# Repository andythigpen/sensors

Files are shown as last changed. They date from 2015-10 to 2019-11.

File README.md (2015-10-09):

# My MySensors Sensors...
Arduino code and supporting files for my [MySensors](http://mysensors.org) sensors (say that 5x fast).

## How the sensors are used

Each sensor node connects wirelessly to a MySensors Serial Gateway attached to a local install of [Home Assistant](https://home-assistant.io) (seen below).  
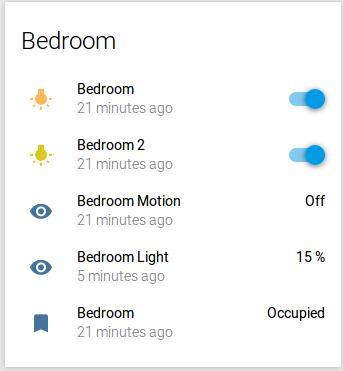
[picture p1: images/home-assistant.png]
Home Assistant


The PIR motion sensor is used to determine presence in a particular room, and the photocell light sensor is used to determine if the lights need to turn off or on based upon the ambient light level in the room and the current setting for the given time of day.  The state of the rooms and household is managed using a [custom Home Assistant module](https://github.com/andythigpen/hass-config/blob/master/custom_components/myhome.py).

## A Finished Sensor Node

### Front View
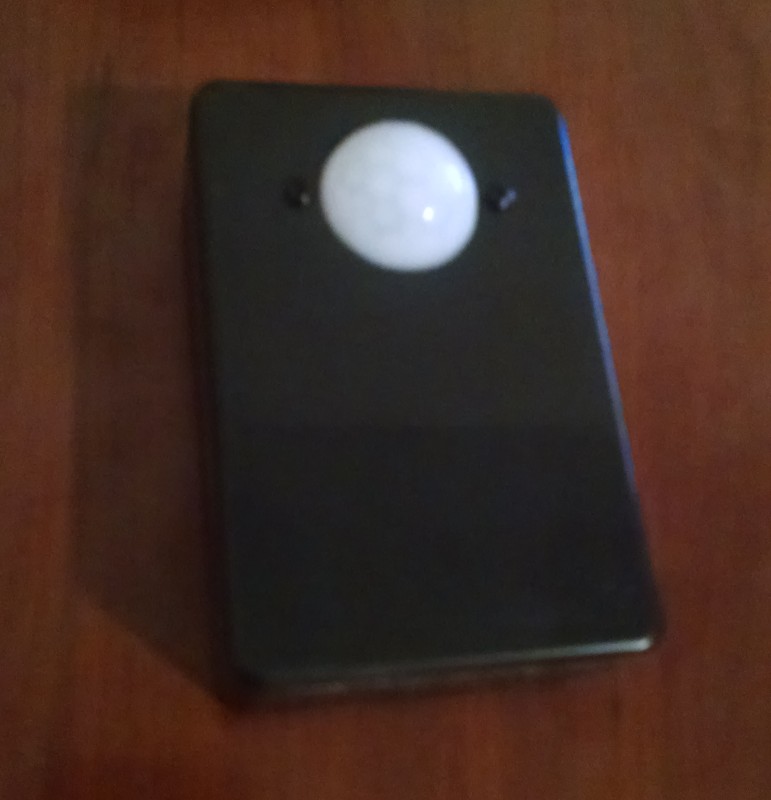
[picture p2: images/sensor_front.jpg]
Sensor Front


_Picture taken with a potato._

It's difficult to tell the size, but the project box is roughly the height and width of a pack of cards.

### Side View
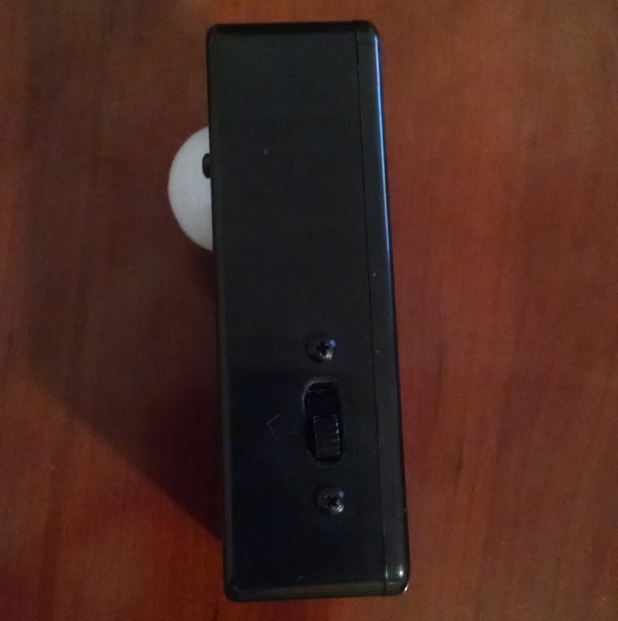
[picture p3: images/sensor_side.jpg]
Sensor Side


_Cutting square holes is harder than it looks._

### Guts View
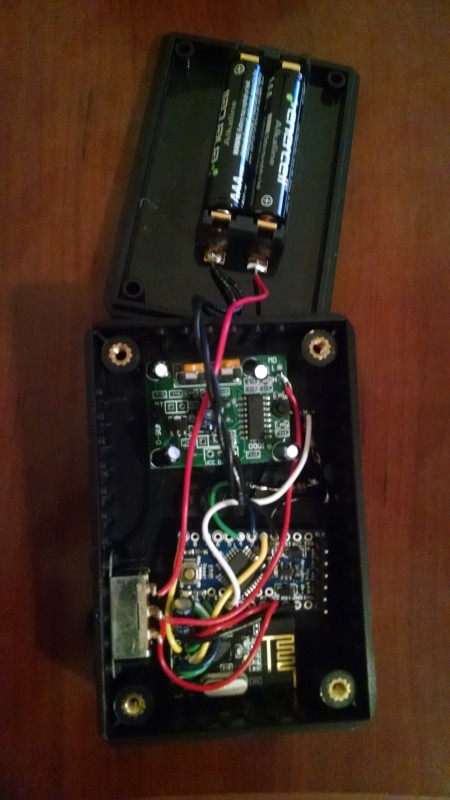
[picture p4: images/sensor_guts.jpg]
Sensor Guts


_It's not pretty but it works._

The battery holder is hot-glued to the lid, and the PIR sensor and power switch are fastened to the box using plastic screws/nuts.  The Arduino and nRF24 radio are not currently permanently attached as there isn't enough room inside the case to move around anyway.

### Schematic
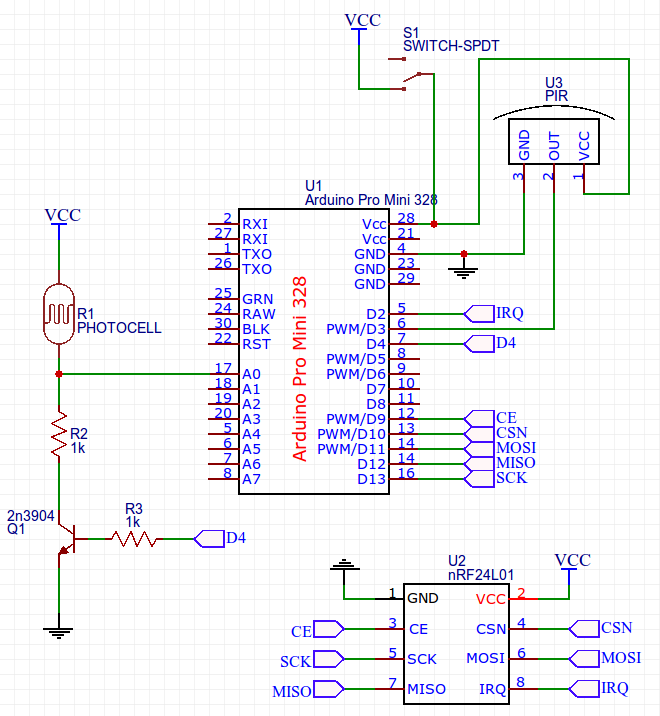
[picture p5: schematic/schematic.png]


## Project Layout
* images/ - pictures of a finished sensor node
* parts/ - CAD drawings of parts and layouts
* schematic/ - schematic files
* src/ - firmware source code

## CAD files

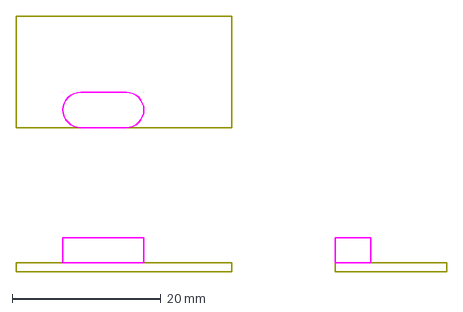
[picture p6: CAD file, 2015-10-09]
parts/#ITEAD-nRF24L01-module.dxf
58.0 x 34.4 mm

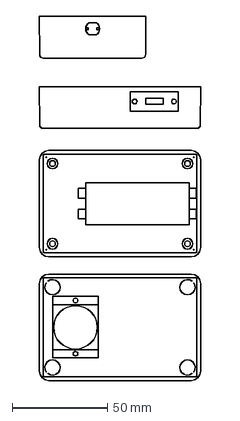
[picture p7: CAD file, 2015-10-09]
parts/sensor_box.dxf
84.8 x 191.6 mm

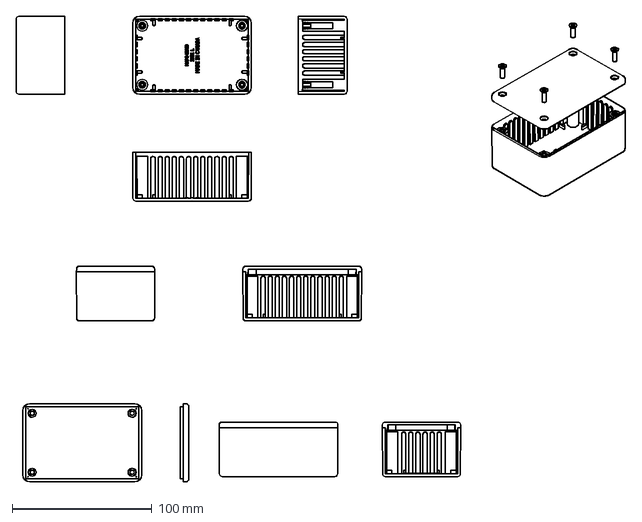
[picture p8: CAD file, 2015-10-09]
parts/1591L.dxf
436.6 x 333.4 mm

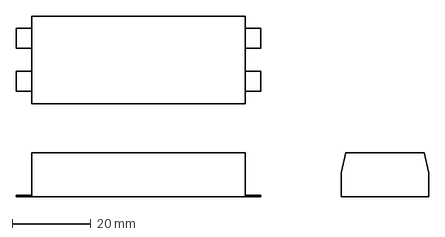
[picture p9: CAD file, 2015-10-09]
parts/1022_smd_aaa_battery_holder.dxf
104.9 x 46.0 mm

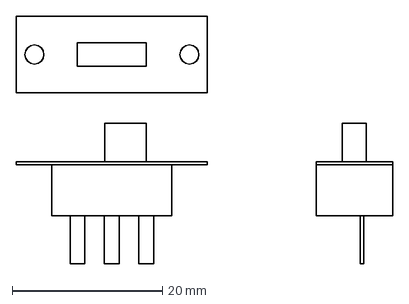
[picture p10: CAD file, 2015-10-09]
parts/spdt_switch.dxf
50.1 x 32.9 mm

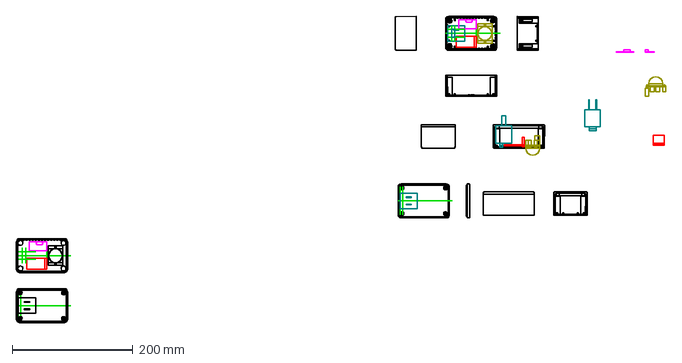
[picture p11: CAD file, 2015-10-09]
parts/sensor_box_large.dxf
1075.3 x 506.9 mm

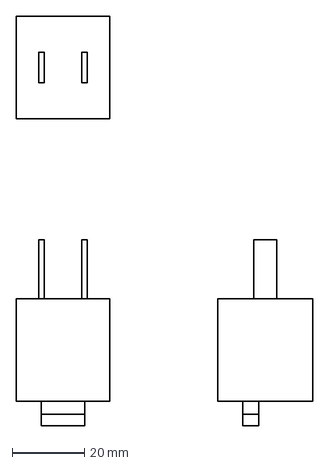
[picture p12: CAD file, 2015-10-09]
parts/apple_charger.dxf
82.2 x 113.7 mm

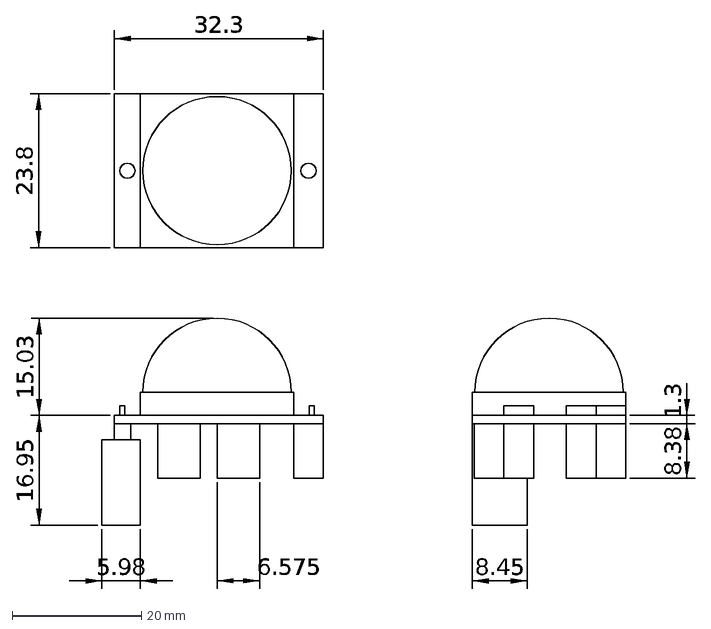
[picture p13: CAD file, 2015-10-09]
parts/pir_sensor.dxf
23.8
16.95
15.03
8.38
1.3
32.3
5.98
8.45
6.575

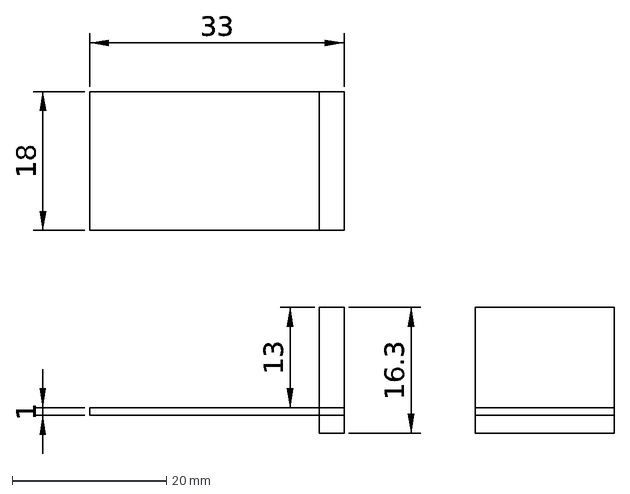
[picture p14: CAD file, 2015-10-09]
parts/arduino_pro_mini.dxf
33
18
16.3
1
13

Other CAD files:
parts/1591L.dwg
parts/ITEAD-nRF24L01-module.dxf

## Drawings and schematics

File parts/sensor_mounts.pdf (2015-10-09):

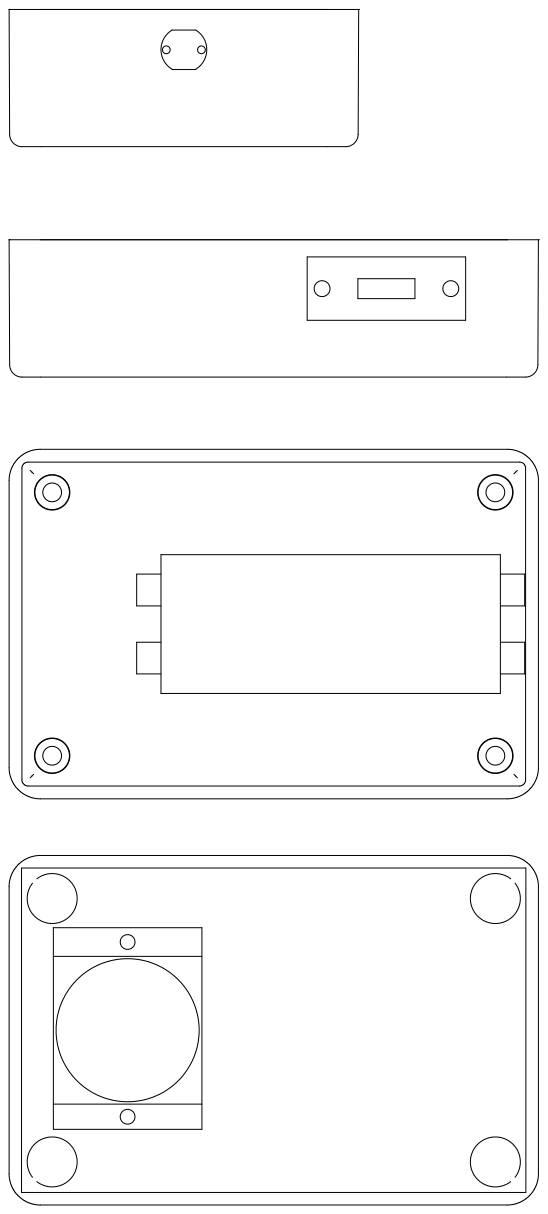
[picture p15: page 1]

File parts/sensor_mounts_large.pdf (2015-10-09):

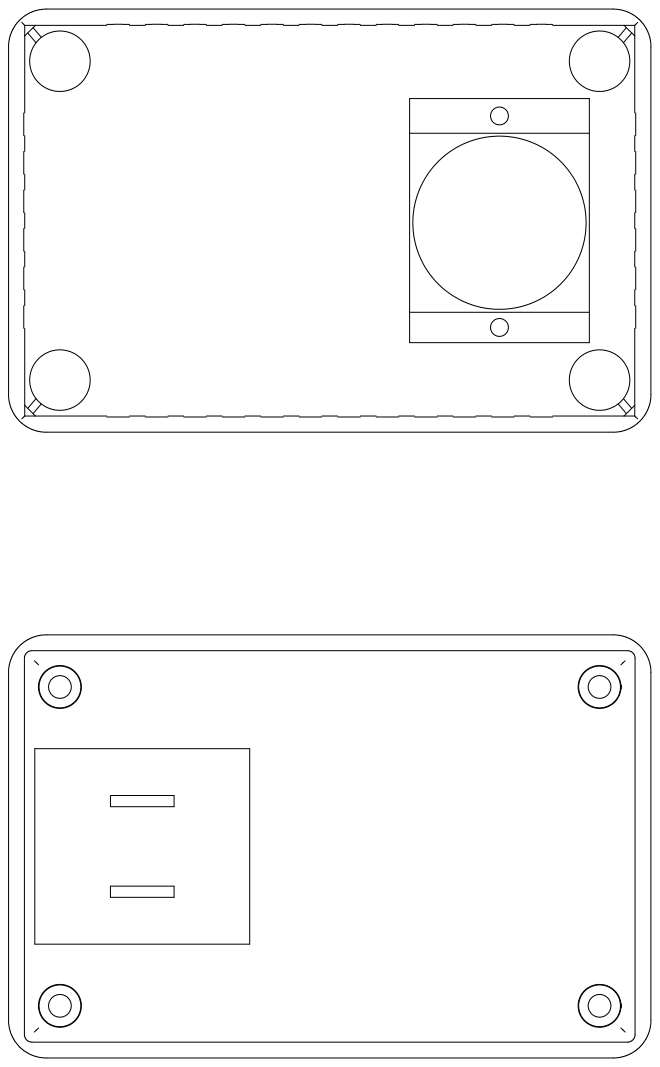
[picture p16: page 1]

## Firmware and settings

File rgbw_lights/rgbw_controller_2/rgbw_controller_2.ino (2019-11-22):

//
// RGBW Neopixel light controller
//
#include <Encoder.h>
#include <Adafruit_NeoPixel.h>
#include <MySensor.h>


// Configuration
#define SENSOR_VERSION      "1.2"
#define DEBUG               1
#define NUM_TOP_LEDS        56
#define NUM_BOTTOM_LEDS     34
#define DEFAULT_BRIGHTNESS  255
#define MAX_MODE            4
#define TIMEOUT_DEBOUNCE    50
#define TIMEOUT_LONG_PRESS  300
#define TIMEOUT_MODE        5000
#define TIMEOUT_STATUS      20000


// Pin definitions
#define PIN_ENC_A       3
#define PIN_ENC_B       A1
#define PIN_LED_R       4
#define PIN_LED_G       5
#define PIN_LED_B       A2
#define PIN_ENC_BTN     A0
#define PIN_NEO1_DIN    6
#define PIN_NEO2_DIN    7


// Sensors
#define MIN_CHILD        1
#define CHILD_TOP_ID     1
#define CHILD_BOTTOM_ID  2
#define MAX_CHILD        3


Encoder myEnc(PIN_ENC_A, PIN_ENC_B);
Adafruit_NeoPixel topStrip = Adafruit_NeoPixel(
    NUM_TOP_LEDS, PIN_NEO1_DIN, NEO_GRBW + NEO_KHZ800);
Adafruit_NeoPixel bottomStrip = Adafruit_NeoPixel(
    NUM_BOTTOM_LEDS, PIN_NEO2_DIN, NEO_GRBW + NEO_KHZ800);
MySensor gw;
MyMessage msg;


const uint8_t PROGMEM gamma8[] = {
    0,  0,  0,  0,  0,  0,  0,  0,  0,  0,  0,  0,  0,  0,  0,  0,
    0,  0,  0,  0,  0,  0,  0,  0,  0,  0,  0,  0,  1,  1,  1,  1,
    1,  1,  1,  1,  1,  1,  1,  1,  1,  2,  2,  2,  2,  2,  2,  2,
    2,  3,  3,  3,  3,  3,  3,  3,  4,  4,  4,  4,  4,  5,  5,  5,
    5,  6,  6,  6,  6,  7,  7,  7,  7,  8,  8,  8,  9,  9,  9, 10,
   10, 10, 11, 11, 11, 12, 12, 13, 13, 13, 14, 14, 15, 15, 16, 16,
   17, 17, 18, 18, 19, 19, 20, 20, 21, 21, 22, 22, 23, 24, 24, 25,
   25, 26, 27, 27, 28, 29, 29, 30, 31, 32, 32, 33, 34, 35, 35, 36,
   37, 38, 39, 39, 40, 41, 42, 43, 44, 45, 46, 47, 48, 49, 50, 50,
   51, 52, 54, 55, 56, 57, 58, 59, 60, 61, 62, 63, 64, 66, 67, 68,
   69, 70, 72, 73, 74, 75, 77, 78, 79, 81, 82, 83, 85, 86, 87, 89,
   90, 92, 93, 95, 96, 98, 99,101,102,104,105,107,109,110,112,114,
  115,117,119,120,122,124,126,127,129,131,133,135,137,138,140,142,
  144,146,148,150,152,154,156,158,160,162,164,167,169,171,173,175,
  177,180,182,184,186,189,191,193,196,198,200,203,205,208,210,213,
  215,218,220,223,225,228,231,233,236,239,241,244,247,249,252,255 };


// Modes
// 0 = brightness
// 1 = white
// 2 = red
// 3 = green
// 4 = blue
#define MODE_BRI  0
#define MODE_W    1
#define MODE_R    2
#define MODE_G    3
#define MODE_B    4


namespace timeout {
    long mode = 0;
    long debounce = 0;
    long longPress = 0;
    long status = 0;
    bool active = false;    // true when user is interacting w/ device

    void resetMode() {
        mode = millis() + TIMEOUT_MODE;
        active = true;
    }
};

namespace state {
    long encoder = 0;       // last position of the encoder
    bool button = LOW;      // last read of the button
    bool pressed = false;   // is a press event in progress
    bool longPress = false; // true when long press detected
    uint8_t mode = 0;       // current interface mode

    void setEncoder(long e) {
        encoder = e;
        myEnc.write(e);
    }

    void setMode(uint8_t m) {
        mode = m;
        if (mode > MAX_MODE)
            mode = 0;
#if DEBUG
        Serial.print("mode:");
        Serial.println(mode);
#endif
        switch (mode) {
            case 1:
                digitalWrite(PIN_LED_R, LOW);
                digitalWrite(PIN_LED_G, LOW);
                digitalWrite(PIN_LED_B, LOW);
                break;
            case 2:
                digitalWrite(PIN_LED_R, LOW);
                digitalWrite(PIN_LED_G, HIGH);
                digitalWrite(PIN_LED_B, HIGH);
                break;
            case 3:
                digitalWrite(PIN_LED_R, HIGH);
                digitalWrite(PIN_LED_G, LOW);
                digitalWrite(PIN_LED_B, HIGH);
                break;
            case 4:
                digitalWrite(PIN_LED_R, HIGH);
                digitalWrite(PIN_LED_G, HIGH);
                digitalWrite(PIN_LED_B, LOW);
                break;
            case 0:
            default:
                digitalWrite(PIN_LED_R, HIGH);
                digitalWrite(PIN_LED_G, HIGH);
                digitalWrite(PIN_LED_B, HIGH);
                break;
        }
    }

    void nextMode() {
        setMode(mode + 1);
    }
};

namespace lights {
    struct LightStrip {
        LightStrip(Adafruit_NeoPixel &s) : strip(s), color(0) {
            prevColor = strip.Color(0, 0, 0, 255);
            animation.color = strip.Color(0, 0, 0, 255);
            animation.bri = DEFAULT_BRIGHTNESS;
            animation.steps = 0;
            animation.duration = 1000000;
            //animation.duration = 0;
            animation.wait = 0;
            animation.prevFrame = 0;
        }
        uint32_t color;
        uint32_t prevColor;
        uint8_t prevBri;
        Adafruit_NeoPixel &strip;

        struct {
            uint32_t color;
            uint8_t bri;
            uint32_t steps;
            uint32_t duration;
            uint32_t wait;
            uint32_t prevFrame;
        } animation;

        void resetAnimation() {
            byte current, to, diff;

            animation.steps = 1;
            animation.prevFrame = 0;
            animation.wait = 0;

            // don't animate anything when interacting directly with the controller
            if (!timeout::active && animation.duration) {
                for (uint8_t i = 0; i < 4; ++i) {
                    current = *((byte *)&color + i);
                    to = *((byte *)&animation.color + i);
                    diff = current > to ? current - to : to - current;
                    animation.steps = max(animation.steps, diff);
#if DEBUG
                    Serial.print("i:");
                    Serial.print(i);
                    Serial.print(" current:");
                    Serial.print(current);
                    Serial.print(" to:");
                    Serial.print(to);
                    Serial.print(" diff:");
                    Serial.print(diff);
                    Serial.print(" steps:");
                    Serial.println(animation.steps);
#endif
                }

                current = strip.getBrightness();
                to = animation.bri;
                diff = current > to ? current - to : to - current;
                animation.steps = max(animation.steps, diff);
                animation.wait = animation.duration / animation.steps;
            }

#if DEBUG
            Serial.print("steps:");
            Serial.print(animation.steps);
            Serial.print(" wait:");
            Serial.print(animation.wait);
            Serial.print(" duration:");
            Serial.println(animation.duration);
#endif
        }

        void animate() {
            // do not use animations for direct interaction
            //if (timeout::active)
            //    animation.steps = 1;

            //if (timeout::active || (animation.steps && micros() - animation.prevFrame > animation.wait))
            if (animation.steps && micros() - animation.prevFrame > animation.wait)
                displayFrame();
        }

        void displayFrame() {
            byte *current, *to;

            animation.prevFrame = micros();
            animation.steps -= 1;

            if (animation.steps == 0) {
                color = animation.color;
                strip.setBrightness(animation.bri);
            }
            else {
                for (uint8_t i = 0; i < 4; ++i) {
                    current = (byte *)&color + i;
                    to = (byte *)&animation.color + i;

                    if (*current > *to)
                        *current -= 1;
                    else if (*current < *to)
                        *current += 1;
                }

                byte bri = strip.getBrightness();
                if (bri > animation.bri)
                    strip.setBrightness(bri - 1);
                else if (bri < animation.bri)
                    strip.setBrightness(bri + 1);
            }

            update();
            draw();
        }

        bool isOn() {
            return color != 0 && animation.bri != 0;
        }

        void getRGBW(char *rgbwStr) {
            sprintf(rgbwStr, "%.6X", color & 0xFFFFFF);
            sprintf(rgbwStr + 6, "%.2X", color >> 24);
        }

        void begin() {
            strip.setBrightness(DEFAULT_BRIGHTNESS);
            strip.begin();
            update();
            draw();
        }

        void update() {
#if 0
            Serial.print("update: ");
            Serial.print(strip.getPin());
            Serial.print(" color:");
            Serial.println(color, HEX);
#endif
            for (uint16_t i = 0; i < strip.numPixels(); ++i) {
                strip.setPixelColor(i, color);
            }
        }

        void toggle(uint8_t m) {
            if (get(m))
                set(m, 0);
            else
                set(m, 255);
#if DEBUG
            Serial.print("toggle: ");
            Serial.print(strip.getPin());
            Serial.print(" mode:");
            Serial.print(m);
            Serial.print(" val:");
            Serial.println(get(m));
#endif
            //update();
        }

        uint8_t get(uint8_t m) {
            switch (m) {
                case MODE_W: return ((uint8_t *)&color)[3];
                case MODE_R: return ((uint8_t *)&color)[2];
                case MODE_G: return ((uint8_t *)&color)[1];
                case MODE_B: return ((uint8_t *)&color)[0];
                case MODE_BRI: return strip.getBrightness();
                default: return 0;
            }
        }

        void set(uint8_t m, uint8_t val) {
            switch (m) {
                case MODE_W: ((uint8_t*)&animation.color)[3] = val; break;
                case MODE_R: ((uint8_t*)&animation.color)[2] = val; break;
                case MODE_G: ((uint8_t*)&animation.color)[1] = val; break;
                case MODE_B: ((uint8_t*)&animation.color)[0] = val; break;
                case MODE_BRI: animation.bri = val; break;
            }

            state::setEncoder(val);
#if DEBUG
            Serial.print("set: ");
            Serial.print(strip.getPin());
            Serial.print(" mode:");
            Serial.print(m);
            Serial.print(" val:");
            Serial.println(val);
#endif
            //update();
            resetAnimation();
        }

        void set(uint8_t r, uint8_t g, uint8_t b, uint8_t w) {
            animation.color = strip.Color(r, g, b, w);
            resetAnimation();
            //update();
        }

        void turnOn() {
            if (prevBri)
                animation.bri = prevBri;
            else
                animation.bri = 255;

            if (animation.color == 0)
                animation.color = strip.Color(0, 0, 0, 255);
            resetAnimation();
        }

        void turnOff() {
            prevBri = animation.bri;
            animation.bri = 0;
            resetAnimation();
        }

        void toggleSwitch(int val) {
            if (val)
                turnOn();
            else
                turnOff();
        }

        void draw() {
#if 0
            Serial.print("draw: ");
            Serial.println(strip.getPin());
#endif
            strip.show();
        }
    };
    LightStrip top(topStrip);
    LightStrip bottom(bottomStrip);

    void updateAll() {
        top.update();
        bottom.update();
    }

    void toggleAll(uint8_t m) {
        if (m == MODE_BRI) {
            if (lights::top.isOn()) {
                lights::top.turnOff();
                lights::bottom.turnOff();
            }
            else {
                lights::top.turnOn();
                lights::bottom.turnOn();
            }
        }
        else {
            lights::top.toggle(m);
            lights::bottom.toggle(m);
        }
    }

    void setAll(uint8_t m, uint8_t val) {
        lights::top.set(m, val);
        lights::bottom.set(m, val);
    }

    void drawAll() {
        top.draw();
        bottom.draw();
    }
};


void setup() {
    gw.begin(receiveMessage, 15);
    gw.sendSketchInfo("RGBW", SENSOR_VERSION);
    gw.present(CHILD_TOP_ID, S_RGBW_LIGHT);
    gw.present(CHILD_BOTTOM_ID, S_RGBW_LIGHT);

    sendStatus();

#if DEBUG
    Serial.println("RGBW Controller start");
#endif

    // setup encoder pins
    pinMode(PIN_LED_R, OUTPUT);
    pinMode(PIN_LED_G, OUTPUT);
    pinMode(PIN_LED_B, OUTPUT);
    pinMode(PIN_ENC_BTN, INPUT);

    digitalWrite(PIN_LED_R, HIGH);
    digitalWrite(PIN_LED_G, HIGH);
    digitalWrite(PIN_LED_B, HIGH);

    lights::top.begin();
    lights::bottom.begin();
}


void loop() {
    readButton();
    readEncoder();

    if (timeout::active && millis() > timeout::mode)
        onTimeoutMode();

    if (millis() > timeout::status)
        onTimeoutStatus();

    lights::top.animate();
    lights::bottom.animate();

    gw.process();
}


// Called when interface timer expires
void onTimeoutMode() {
#if DEBUG
    Serial.println("timeout mode");
#endif
    state::setMode(0);
    state::setEncoder(lights::top.get(state::mode));
    sendStatus();
    timeout::active = false;
}

// Called when status timer expires
void onTimeoutStatus() {
#if DEBUG
    Serial.println("timeout status");
#endif
    sendStatus();
    timeout::status = millis() + TIMEOUT_STATUS;
}


// Reads the button state and performs an action on change
void readButton() {
    bool btn = digitalRead(PIN_ENC_BTN);

    // button press start
    if (btn == HIGH && state::button == LOW &&
        (millis()  > timeout::debounce)) {
#if DEBUG
        Serial.println("press start");
#endif
        timeout::debounce = millis() + TIMEOUT_DEBOUNCE;
        timeout::longPress = millis() + TIMEOUT_LONG_PRESS;
        state::pressed = true;
        state::longPress = false;
    }

    if (state::pressed && (millis() > timeout::debounce)) {
        timeout::resetMode();

        if (millis() > timeout::longPress && !state::longPress) {
            onLongPress();
            state::longPress = true;
        }

        if (btn == LOW && state::button == HIGH) {
#if DEBUG
            Serial.println("press end");
#endif
            if (!state::longPress) {
                onShortPress();
            }
            state::pressed = false;
            timeout::debounce = millis() + TIMEOUT_DEBOUNCE;
        }
    }
    state::button = btn;
}


// Called on short button press events
void onShortPress() {
#if DEBUG
    Serial.println("short press");
#endif
    lights::toggleAll(state::mode);
    lights::drawAll();
}


// Called on long button press events
void onLongPress() {
#if DEBUG
    Serial.println("long press");
#endif
    state::nextMode();
    state::setEncoder(lights::top.get(state::mode));
}


// Handles on change event for encoder
void onChangeEncoder() {
#if DEBUG
    Serial.print("encoder:");
    Serial.print(state::encoder);
    Serial.print(" mode:");
    Serial.println(state::mode);
#endif
    lights::setAll(state::mode, state::encoder);
    lights::updateAll();
    lights::drawAll();
}

// Reads the encoder value and performs an action on change
void readEncoder() {
    long pos = myEnc.read();
    if (pos == state::encoder)
        return;

    if (pos > 255) {
        pos = 255;
        myEnc.write(255);
    }
    else if (pos < 0) {
        pos = 0;
        myEnc.write(0);
    }
    state::encoder = pos;
    timeout::resetMode();
    onChangeEncoder();
}

void sendStatus() {
    char rgbwStr[9];
    uint8_t val;

    // top light status
    msg.setSensor(CHILD_TOP_ID);
    msg.setType(V_RGBW);
    lights::top.getRGBW(rgbwStr);
    gw.send(msg.set(rgbwStr));

    msg.setType(V_STATUS);
    gw.send(msg.set(lights::top.isOn()));

    msg.setType(V_PERCENTAGE);
    val = lights::top.get(MODE_BRI);
    gw.send(msg.set(map(val, 0, 255, 0, 100)));

    msg.setType(V_VAR2);
    gw.send(msg.set(timeout::active));

    // bottom light status
    msg.setSensor(CHILD_BOTTOM_ID);
    msg.setType(V_RGBW);
    lights::bottom.getRGBW(rgbwStr);
    gw.send(msg.set(rgbwStr));

    msg.setType(V_STATUS);
    gw.send(msg.set(lights::bottom.isOn()));

    msg.setType(V_PERCENTAGE);
    val = lights::bottom.get(MODE_BRI);
    gw.send(msg.set(map(val, 0, 255, 0, 100)));

    msg.setType(V_VAR2);
    gw.send(msg.set(timeout::active));

    timeout::status = millis() + TIMEOUT_STATUS;
}

void receiveMessage(const MyMessage &message) {
    if (message.type == V_RGBW) {
        char rgbwStr[9];
        String hexstring = message.getString();
        hexstring.toCharArray(rgbwStr, sizeof(rgbwStr));

        unsigned long value = strtoul(rgbwStr, NULL, 16);
        byte w = value & 0xFF;
        byte r = value >> 24;
        byte g = value >> 16 & 0xFF;
        byte b = value >> 8 & 0xFF;

        if (message.sensor == CHILD_TOP_ID) {
            lights::top.set(r, g, b, w);
            //lights::top.setAnimation(new lights::FadeAnimation(&lights::top, lights::top.strip.Color(r, g, b, w), lights::animationDuration));
        }
        else if (message.sensor == CHILD_BOTTOM_ID) {
            lights::bottom.set(r, g, b, w);
            //lights::bottom.setAnimation(new lights::FadeAnimation(&lights::bottom, lights::bottom.strip.Color(r, g, b, w), lights::animationDuration));
        }

#if DEBUG
        Serial.print("child:");
        Serial.print(message.sensor);
        Serial.print(" V_RGBW:");
        Serial.println(value, HEX);
#endif

        // send optimistic response:
        msg.setSensor(message.sensor);
        msg.setType(V_RGBW);
        gw.send(msg.set(hexstring.c_str()));
    }

    if (message.type == V_STATUS) {
        int value = message.getInt();
        if (message.sensor == CHILD_TOP_ID)
            lights::top.toggleSwitch(value);
        else if (message.sensor == CHILD_BOTTOM_ID)
            lights::bottom.toggleSwitch(value);

#if DEBUG
        Serial.print("child:");
        Serial.print(message.sensor);
        Serial.print(" V_STATUS:");
        Serial.println(value);
#endif

        // send optimistic response:
        msg.setSensor(message.sensor);
        msg.setType(V_STATUS);
        gw.send(msg.set(value));
    }

    if (message.type == V_PERCENTAGE) {
        int value = message.getInt();
        int mapped = map(value, 0, 100, 0, 255);
        if (message.sensor == CHILD_TOP_ID)
            lights::top.set(MODE_BRI, mapped);
        else if (message.sensor == CHILD_BOTTOM_ID)
            lights::bottom.set(MODE_BRI, mapped);
#if DEBUG
        Serial.print("child:");
        Serial.print(message.sensor);
        Serial.print(" V_PERCENTAGE:");
        Serial.println(value);
#endif

        // send optimistic response:
        msg.setSensor(message.sensor);
        msg.setType(V_PERCENTAGE);
        gw.send(msg.set(value));
    }

    if (message.type == V_VAR1) {
        uint32_t value = message.getULong();
        if (message.sensor == CHILD_TOP_ID)
            lights::top.animation.duration = value;
        else if (message.sensor == CHILD_BOTTOM_ID)
            lights::bottom.animation.duration = value;
#if DEBUG
        Serial.print("child:");
        Serial.print(message.sensor);
        Serial.print(" V_VAR1:");
        Serial.println(value);
#endif

        // send optimistic response:
        msg.setSensor(message.sensor);
        msg.setType(V_VAR1);
        gw.send(msg.set(value));
    }
}

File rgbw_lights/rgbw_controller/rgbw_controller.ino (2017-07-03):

//
// RGBW Neopixel light controller
//
#include <Encoder.h>
#include <Adafruit_NeoPixel.h>
//#define MY_DEBUG 1
#include <MySensor.h>


// Configuration
#define SENSOR_VERSION      "1.0"
#define DEBUG               1
#define NUM_LEDS            90
#define DEFAULT_BRIGHTNESS  255
#define MAX_MODE            3
#define TIMEOUT_DEBOUNCE    100
#define TIMEOUT_LONG_PRESS  750
#define TIMEOUT_MODE        3000


// Pin definitions
#define PIN_ENC_A       3
#define PIN_ENC_B       A1
#define PIN_LED_R       4
#define PIN_LED_G       5
#define PIN_LED_B       A2
#define PIN_ENC_BTN     A0
#define PIN_NEO_DIN     6


// Sensors
//#define LIGHTS_BOTTOM_RIGHT  1
//#define LIGHTS_BOTTOM_LEFT   2
//#define LIGHTS_TOP           3
#define CHILD_ID  1

Encoder myEnc(PIN_ENC_A, PIN_ENC_B);
Adafruit_NeoPixel strip = Adafruit_NeoPixel(NUM_LEDS, PIN_NEO_DIN, NEO_GRBW + NEO_KHZ800);
MySensor gw;
MyMessage dimmerMsg(CHILD_ID, V_PERCENTAGE);
MyMessage lightMsg(CHILD_ID, V_STATUS);
MyMessage rgbMsg(CHILD_ID, V_RGB);


const uint8_t PROGMEM gamma8[] = {
    0,  0,  0,  0,  0,  0,  0,  0,  0,  0,  0,  0,  0,  0,  0,  0,
    0,  0,  0,  0,  0,  0,  0,  0,  0,  0,  0,  0,  1,  1,  1,  1,
    1,  1,  1,  1,  1,  1,  1,  1,  1,  2,  2,  2,  2,  2,  2,  2,
    2,  3,  3,  3,  3,  3,  3,  3,  4,  4,  4,  4,  4,  5,  5,  5,
    5,  6,  6,  6,  6,  7,  7,  7,  7,  8,  8,  8,  9,  9,  9, 10,
   10, 10, 11, 11, 11, 12, 12, 13, 13, 13, 14, 14, 15, 15, 16, 16,
   17, 17, 18, 18, 19, 19, 20, 20, 21, 21, 22, 22, 23, 24, 24, 25,
   25, 26, 27, 27, 28, 29, 29, 30, 31, 32, 32, 33, 34, 35, 35, 36,
   37, 38, 39, 39, 40, 41, 42, 43, 44, 45, 46, 47, 48, 49, 50, 50,
   51, 52, 54, 55, 56, 57, 58, 59, 60, 61, 62, 63, 64, 66, 67, 68,
   69, 70, 72, 73, 74, 75, 77, 78, 79, 81, 82, 83, 85, 86, 87, 89,
   90, 92, 93, 95, 96, 98, 99,101,102,104,105,107,109,110,112,114,
  115,117,119,120,122,124,126,127,129,131,133,135,137,138,140,142,
  144,146,148,150,152,154,156,158,160,162,164,167,169,171,173,175,
  177,180,182,184,186,189,191,193,196,198,200,203,205,208,210,213,
  215,218,220,223,225,228,231,233,236,239,241,244,247,249,252,255 };


// LED color/settings
// ordered wrgb because that's the order of "modes" (white most used)
uint8_t wrgb[] = {0, 0, 0, 0};
uint8_t prev_wrgb[] = {0, 0, 0, 0};
uint8_t brightness = DEFAULT_BRIGHTNESS;
bool onoff = false;


// Physical UI (encoder/button)
long oldPosition  = -999;
bool btnPressed = false;
bool btnState = HIGH;
bool longPressDone = false;
int mode = -1;
unsigned long lastModeUpdate = 0;
unsigned long lastBtnUpdate = 0;


// forward declarations;
void updateLEDs(uint8_t from=0, uint8_t to=0);
void updateButton();
void updateEncoder();



void setup() {
  gw.begin(incomingMessage, 15);
  gw.sendSketchInfo("RGBW", SENSOR_VERSION);
  gw.present(CHILD_ID, S_RGB_LIGHT);

  //gw.send(lightMsg.set(0));
  //gw.send(dimmerMsg.set(0));
  //gw.send(rgbMsg.set("000000"));
  sendCurrentState();

  // setup encoder LED pins
  pinMode(PIN_LED_R, OUTPUT);
  pinMode(PIN_LED_G, OUTPUT);
  pinMode(PIN_LED_B, OUTPUT);
  pinMode(PIN_ENC_BTN, INPUT);

  digitalWrite(PIN_LED_R, HIGH);
  digitalWrite(PIN_LED_G, HIGH);
  digitalWrite(PIN_LED_B, HIGH);

  strip.setBrightness(brightness);
  strip.begin();
  strip.show();

  Serial.println("RGBW Controller start");
  setMode(-1);
  delay(50);
}


void loop() {
  updateButton();
  updateEncoder();  

  // timeout the current mode after TIMEOUT_MODE
  if (millis() - TIMEOUT_MODE > lastModeUpdate && mode >= 0) {
    setMode(-1);
  }

  gw.process();
}


void setMode(int newMode) {
  mode = newMode;
  if (mode > MAX_MODE) {
    mode = 0;
  }

#if DEBUG
  Serial.print("mode: ");
  Serial.println(mode);
#endif

  switch (mode) {
    case 0:
      digitalWrite(PIN_LED_R, LOW);
      digitalWrite(PIN_LED_G, LOW);
      digitalWrite(PIN_LED_B, LOW);
      break;
    case 1:
      digitalWrite(PIN_LED_R, LOW);
      digitalWrite(PIN_LED_G, HIGH);
      digitalWrite(PIN_LED_B, HIGH);
      break;
    case 2:
      digitalWrite(PIN_LED_R, HIGH);
      digitalWrite(PIN_LED_G, LOW);
      digitalWrite(PIN_LED_B, HIGH);
      break;
    case 3:
      digitalWrite(PIN_LED_R, HIGH);
      digitalWrite(PIN_LED_G, HIGH);
      digitalWrite(PIN_LED_B, LOW);
      break;
    default:
      digitalWrite(PIN_LED_R, HIGH);
      digitalWrite(PIN_LED_G, HIGH);
      digitalWrite(PIN_LED_B, HIGH);
      break;
  }
}

void resetLEDs() {
    wrgb[0] = wrgb[1] = wrgb[2] = wrgb[3] = 0;
    myEnc.write(0);
}


void updateButton() {
  bool currentState = digitalRead(PIN_ENC_BTN);

  if (currentState == HIGH && btnState == LOW &&
      (millis() - TIMEOUT_DEBOUNCE > lastBtnUpdate)) {
    Serial.println("press start");
    lastBtnUpdate = millis();
    btnPressed = true;
    longPressDone = false;
  }

  if (btnPressed && (millis() - TIMEOUT_DEBOUNCE > lastBtnUpdate)) {
    lastModeUpdate = millis();

    if (millis() - lastBtnUpdate > TIMEOUT_LONG_PRESS && !longPressDone) {
        //Serial.println("long press");
        // long press action == toggle current color
        //lastModeUpdate = millis();
        if (mode >= 0) {
          if (wrgb[mode] == 0) {
            wrgb[mode] = 255;
          }
          else {
            wrgb[mode] = 0;
          }
          myEnc.write(wrgb[mode]);
        }
        else {
          //wrgb[0] = wrgb[1] = wrgb[2] = wrgb[3] = 0;
          //myEnc.write(0);
          resetLEDs();
        }
        updateLEDs();
        sendCurrentState();
        longPressDone = true;
    }
    
    if (currentState == LOW && btnState == HIGH) {
      Serial.print("press end: ");
      if (millis() - lastBtnUpdate > TIMEOUT_LONG_PRESS) {
        Serial.println("long press");
      }
      else {
        Serial.println("short press");
        setMode(mode + 1);
        myEnc.write(wrgb[mode]);
      }
      btnPressed = false;
      lastBtnUpdate = millis();
    }
  }
  btnState = currentState;
}


void updateEncoder() {
  long newPosition = myEnc.read();
  if (newPosition != oldPosition) {
    oldPosition = newPosition;
    
    if (newPosition > 255) {
      newPosition = 255;
      myEnc.write(255);
    }
    else if (newPosition < 0) {
      newPosition = 0;
      myEnc.write(0);
    }

    if (mode < 0) {
      if (!wrgb[0] && !wrgb[1] && !wrgb[2] && !wrgb[3]) {
        setMode(0);
        updateLEDBrightness(DEFAULT_BRIGHTNESS);
      }
      else {
        updateLEDBrightness(newPosition);
      }
    }
    else {
      wrgb[mode] = newPosition;
      updateLEDs();
    }
    lastModeUpdate = millis();

#if DEBUG
    Serial.print("mode: ");
    Serial.print(mode);
    Serial.print(", val: ");
    Serial.println(newPosition);
#endif

    //wrgb[mode] = newPosition;
    //updateLEDs();
    sendCurrentState();
  }
}
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

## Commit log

2015-10-09 Initial import.
    [#ITEAD-nRF24L01-module.dxf, 1022_smd_aaa_battery_holder.dxf, 1591L.dwg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]
2015-10-09 Update incorrect schematic.
2015-12-19 Add support for reading voltage of boost converter.
    Instead of using the internal Vcc trick to determine battery voltage,
    read pin A2 which should be connected to the battery terminal w/ at
    least a 10k resistor (so power doesn't feed back through the protection
    diodes of the pin).
    [motion.ino]
2015-12-28 Only report motion on change.
    Light/battery are now only reported when no interrupt occurs and
    the mcu will sleep afterwards to prevent false triggers.
    [motion.ino]
2016-01-19 Add firmware for RFID presence sensor.
2016-01-22 Add sketch info to RFID sensor.
    Switch type to scene controller for use with Home Assistant.
2016-02-22 Enable repeater mode for motion sensors plugged in.
2017-07-04 Add bed occupancy sensor.
2017-08-27 Fix issue with reported RGBW brightness range.
    [rgbw_controller_2.ino]
2017-09-04 Use a running average and peak detection.
    Calculate a running average and use peak detection in an attempt to
    eliminate false positives. Utilizes a noise band that minimally affects
    the running average. Values outside of the noise band have a greater
    effect on the running average. Finally, values outside of 2x the noise
    band are completely ignored, as they're assumed to be anomalous.
    Also:
    * Reduces the number of pads (2 broke).
    * Adds a trigger limit so that at least 2 pads must be active for
    presence detection.
    * Longer calibration on startup w/ a greater initial delay before
    performing calibration.
    [bed_sensor.ino]
2019-11-22 Simplify sampling and improve calibration.
2019-11-22 Send custom variable for local control override.
    The HA controller uses this variable to differentiate between normal
    status updates and updates that occur because the encoder was manually
    changed.
2019-11-22 Update bed sensor to also send values.
    LWM and avg so that they can be graphed & potentially used for other
    automations.
